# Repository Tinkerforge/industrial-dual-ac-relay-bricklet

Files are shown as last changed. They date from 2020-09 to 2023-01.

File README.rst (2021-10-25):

Industrial Dual AC Relay Bricklet
=================================

This repository contains the firmware source code and the hardware design
files. The documentation generator configs can be found at
https://github.com/Tinkerforge/generators

Repository Content
------------------

software/:
 * examples/: Examples for all supported languages
 * build/: Compiled files
 * src/: Source code of firmware
 * Makefile: Makefile to build project

hardware/:
 * Contains KiCad project files and additionally schematics as PDF

datasheets/:
 * Contains datasheets for sensors and complex ICs that are used

Hardware
--------

The hardware is designed with the open source EDA Suite KiCad
(http://www.kicad.org). Before you are able to open the files,
you have to install the Tinkerforge kicad-libraries
(https://github.com/Tinkerforge/kicad-libraries). You can either clone
them directly in hardware/ or clone them in a separate folder and
symlink them into hardware/
(ln -s kicad_path/kicad-libraries project_path/hardware). After that you
can open the .pro file in hardware/ with KiCad and from there view and
modify the schematics and the PCB layout.

Software
--------

If you want to do your own Brick/Bricklet firmware development we highly
recommend that you use our build environment setup script and read the
tutorial (https://www.tinkerforge.com/en/doc/Tutorials/Tutorial_Build_Environment/Tutorial.html).

To compile the C code we recommend you to install the newest GNU Arm Embedded
Toolchain (https://launchpad.net/gcc-arm-embedded/+download).
You also need to install bricklib2 (https://github.com/Tinkerforge/bricklib2).

You can either clone it directly in software/src/ or clone it in a
separate folder and symlink it into software/src/
(ln -s bricklib_path/bricklib2 project_path/software/src/). Finally make sure to
have CMake installed (http://www.cmake.org/cmake/resources/software.html).

After that you can build the firmware by invoking make in software/.
The firmware (.zbin) can then be found in software/build/ and uploaded
with brickv (click button "Flashing" on start screen).

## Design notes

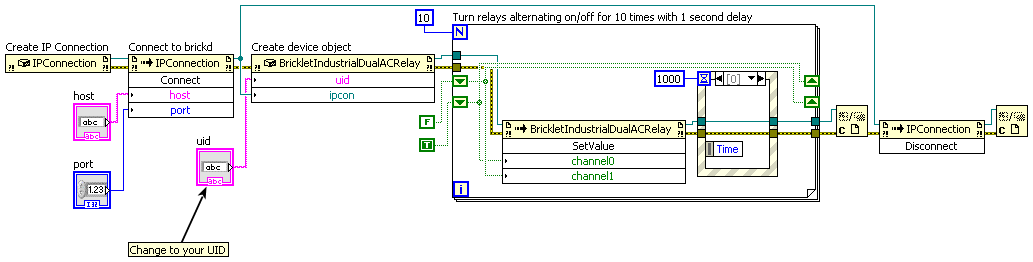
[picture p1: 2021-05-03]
software/examples/labview/Example Simple.vi.png

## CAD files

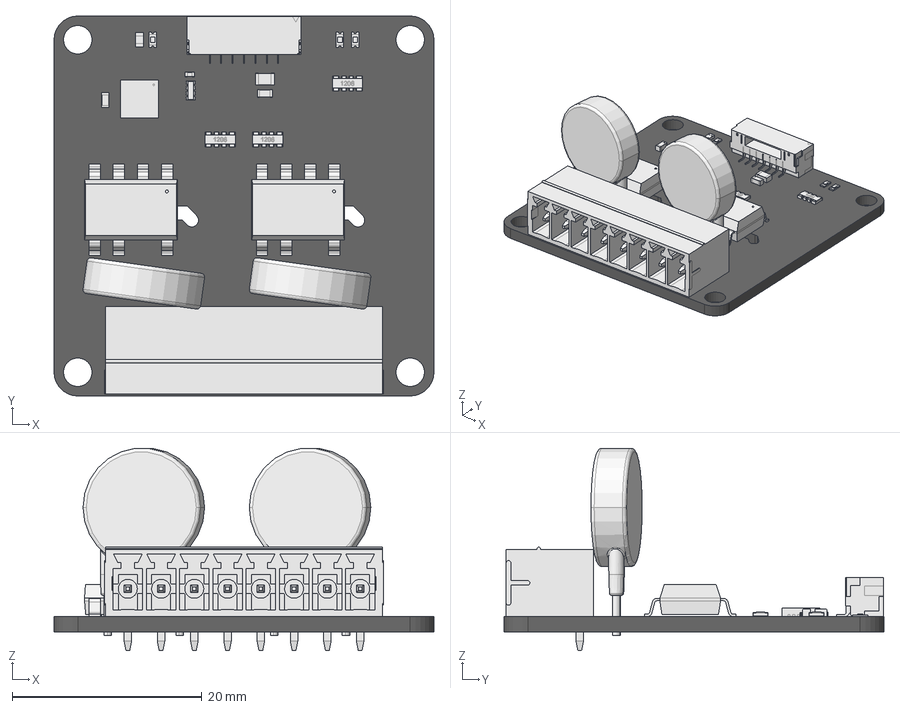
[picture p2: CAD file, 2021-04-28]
hardware/industrial-dual-ac-relay.FCStd
40.0 x 40.0 x 21.3 mm
Pcb_ce84
RP3_Compound_5B27795D
R4_Var_10mm_5F27D5DB
RP2_Cut_5A58BB7E
U1_QFN-24_4x4mm_Pitch0.5mm_5F27E068
C1_C_0603_5B2778F5
C2_C_0402_5B2778FA
C3_C_0805_5B2778FF
C4_C_0603_5B277904
D1_Compound_5B277909
D2_Compound_5F27DD51
D5_Compound_5B27791D
P1_BrickletConn_7pin_5B277922
P2_8er_Phoenix_Buchse_5B27792E
R5_R_0603_5B27794D
RP1_Compound_5B277952
R1_Var_10mm_5F27E3CD
RP4_Compound_5F27D5EB

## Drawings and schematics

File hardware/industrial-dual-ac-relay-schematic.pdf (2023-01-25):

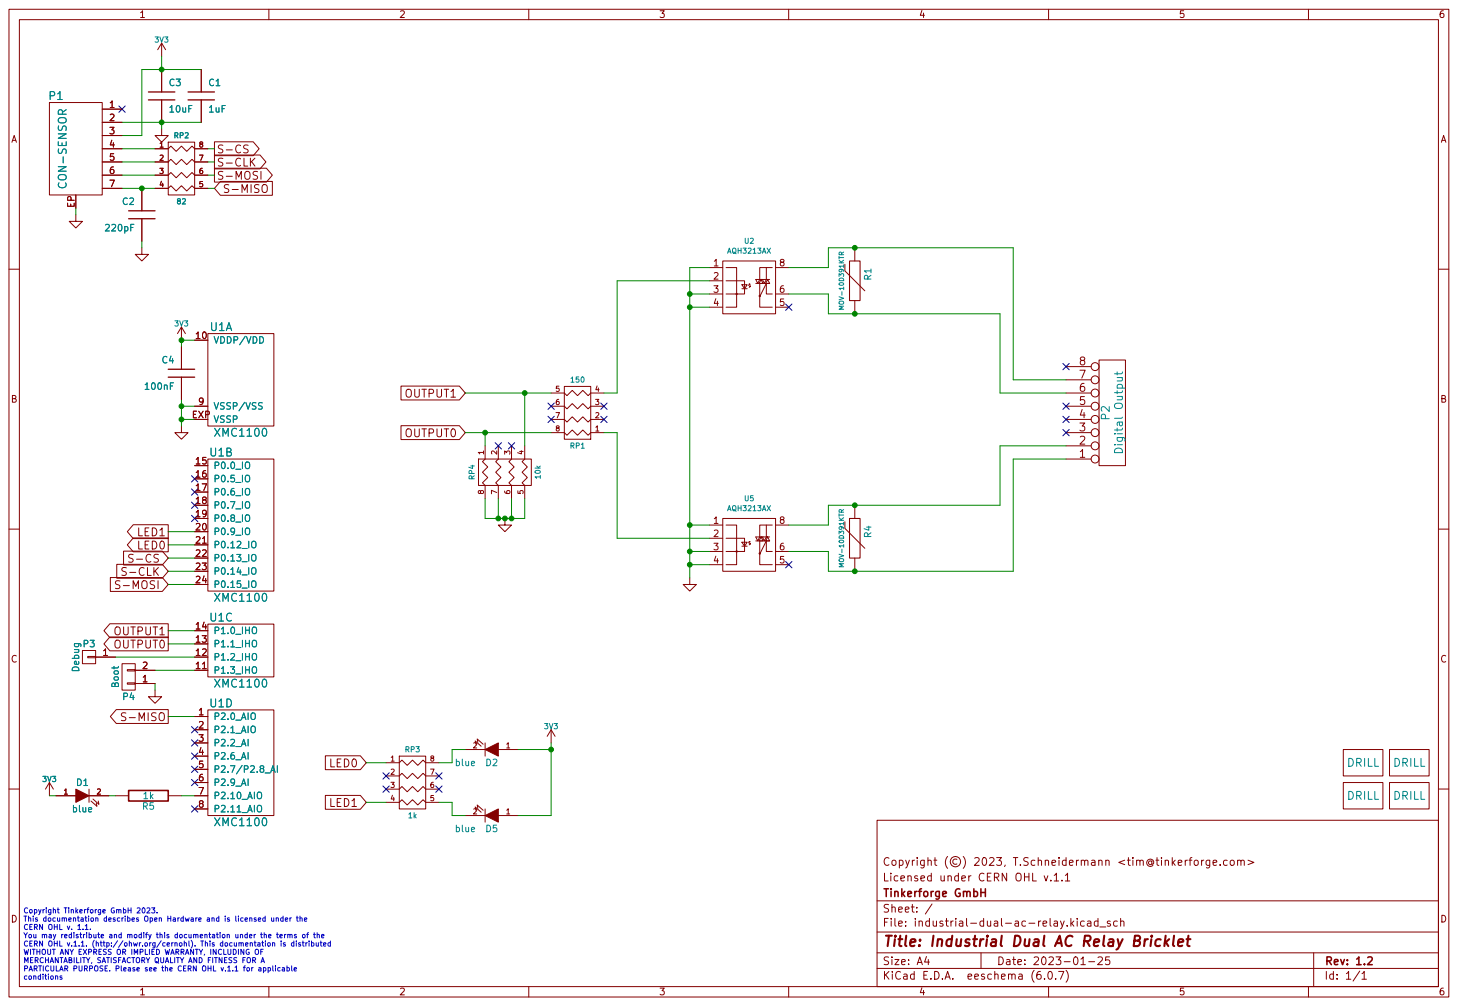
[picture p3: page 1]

Licensed under CERN OHL v.1.1
File: industrial-dual-ac-relay.kicad_sch Sheet: / Tinkerforge GmbH

Copyright Tinkerforge GmbH 2023. This documentation describes Open Hardware and is licensed under the CERN OHL v. 1.1. You may redistribute and modify this documentation under the terms of the CERN OHL v.1.1. (http://ohwr.org/cernohl). This documentation is distributed WITHOUT ANY EXPRESS OR IMPLIED WARRANTY, INCLUDING OF MERCHANTABILITY, SATISFACTORY QUALITY AND FITNESS FOR A

Id: 1/1 Title: Industrial Dual AC Relay Bricklet

PARTICULAR PURPOSE. Please see the CERN OHL v.1.1 for applicable

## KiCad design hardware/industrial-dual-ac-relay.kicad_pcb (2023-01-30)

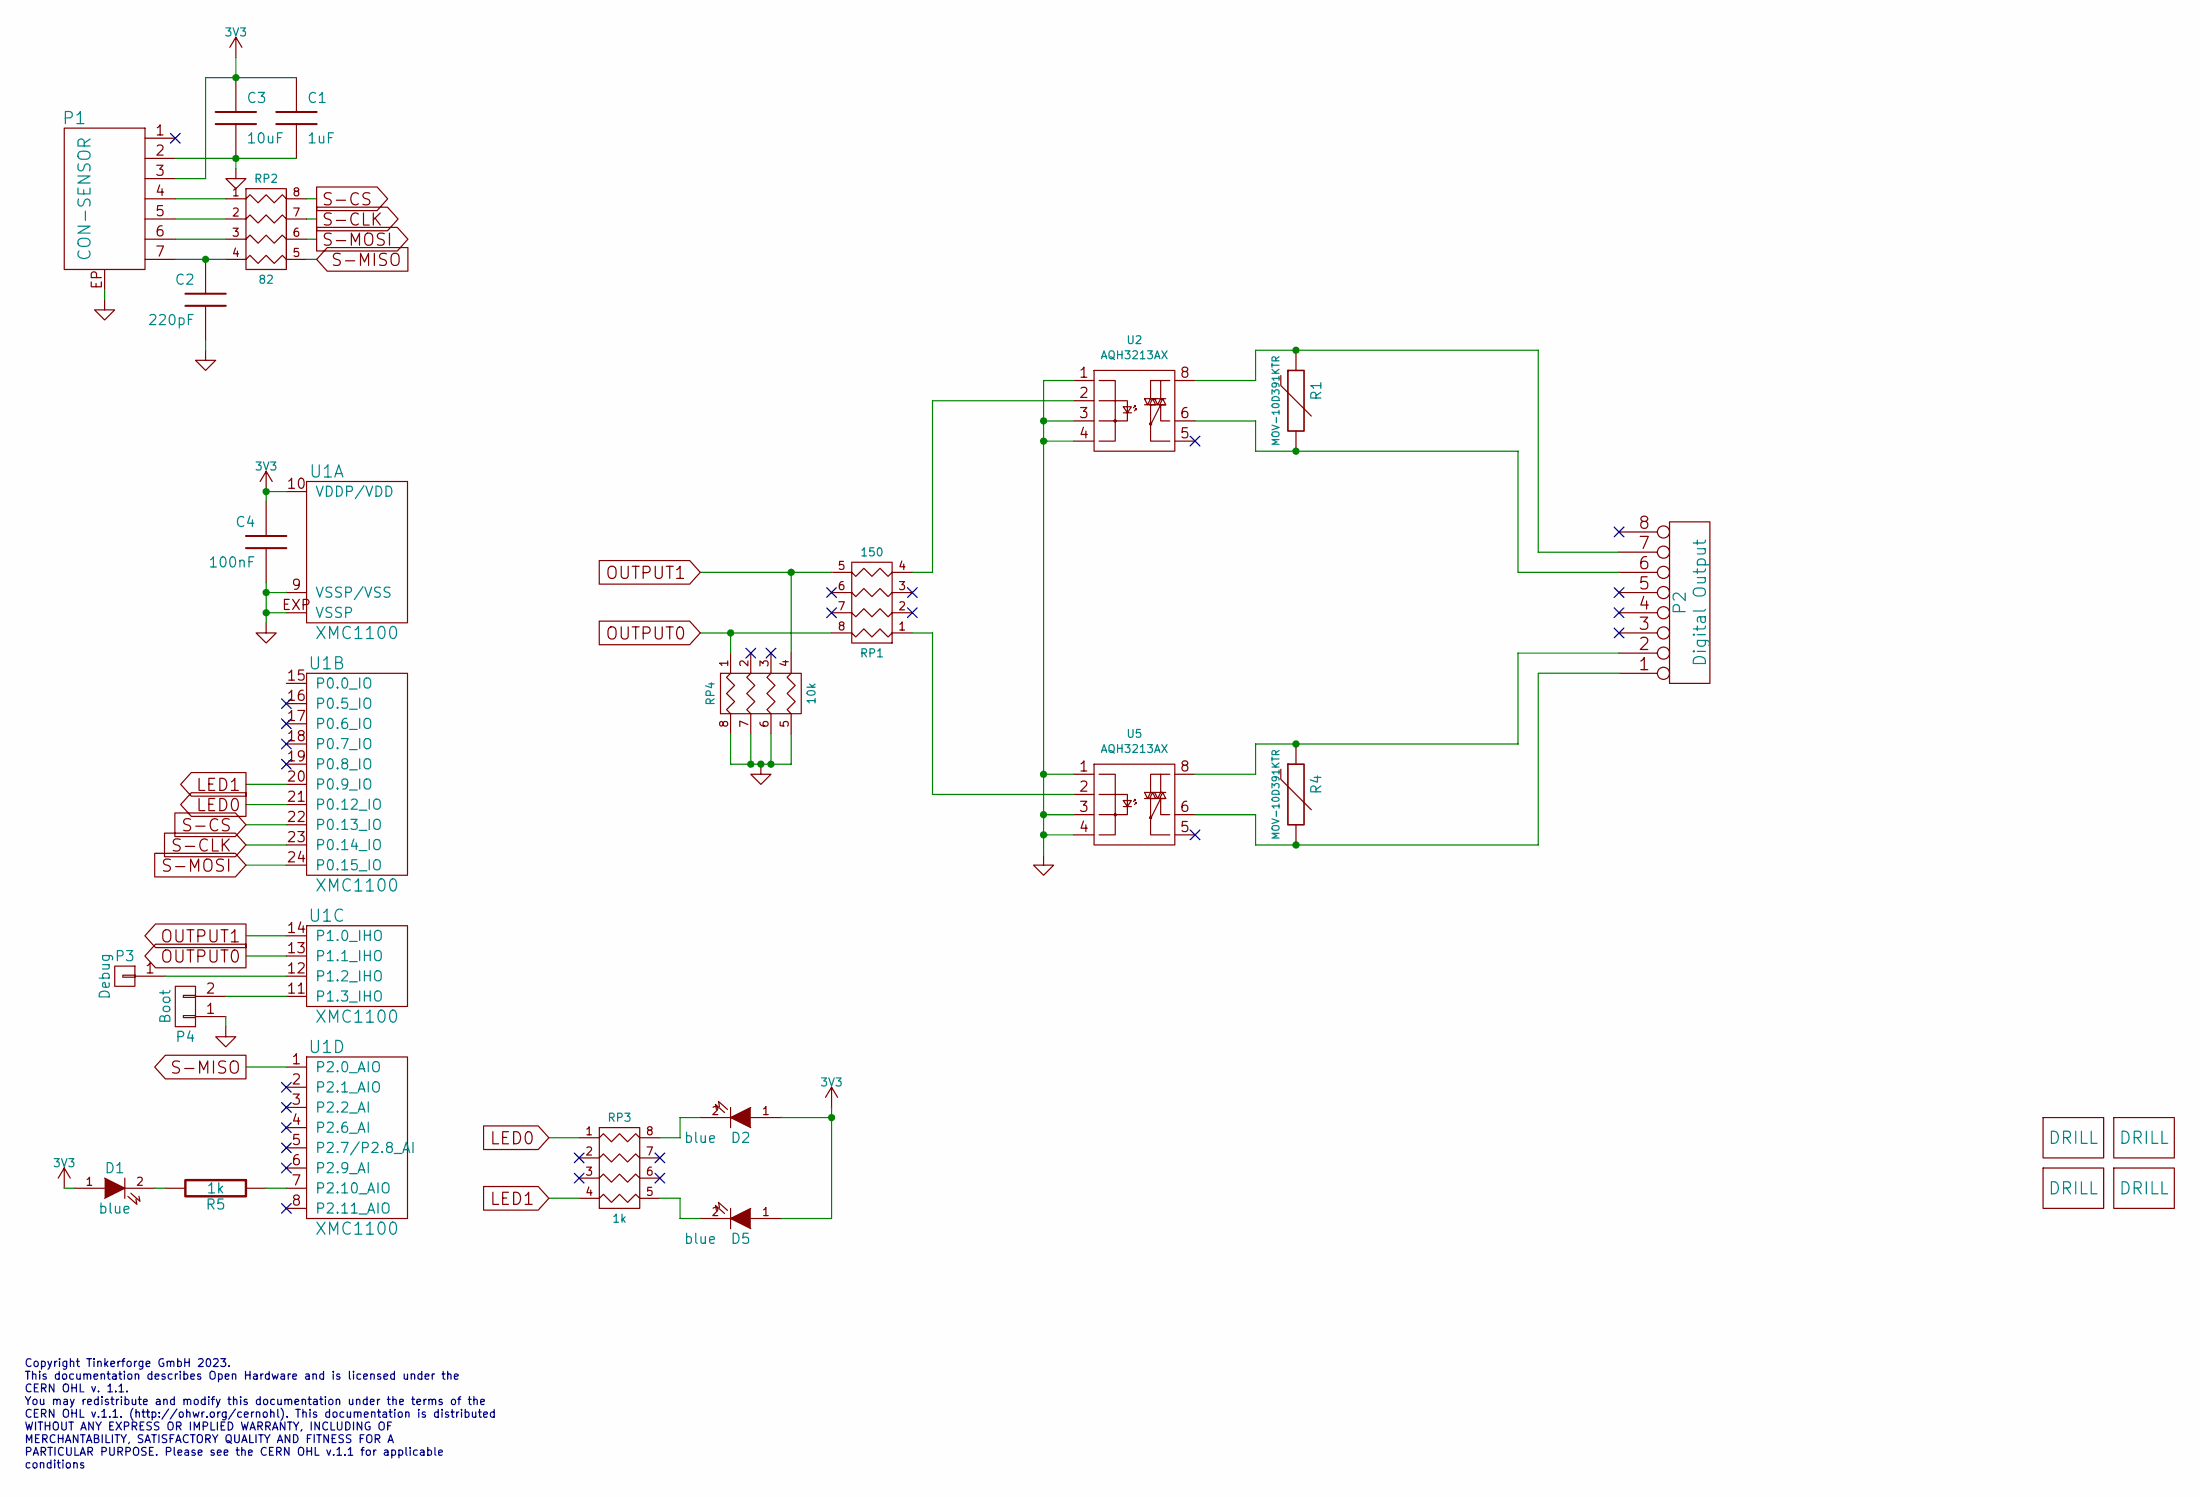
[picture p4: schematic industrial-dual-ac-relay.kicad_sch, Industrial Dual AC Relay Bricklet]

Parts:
C1: 1uF; C0603F
C2: 220pF; C0402F
C3: 10uF; C0805
C4: 100nF; C0603F
D1, D2, D5: blue; D0603F
P1: CON-SENSOR; CON-SENSOR2
P2: Digital Output; OQ_8P_230V
P3: Debug; DEBUG_PAD
P4: Boot; SolderJumper
R1, R4: MOV-10D391KTR; VAR_10mm
R5: 1k; R0603F
RP1: 150; 0603X4
RP2: 82; 4X0402
RP3: 1k; 0603X4
RP4: 10k; 0603X4
U1: XMC1100; QFN24-4x4mm-0.5mm
U2, U5: AQH3213AX; AQ-H
U7, U8, U9: DRILL; DRILL_NP
Ue1: DRILL; DRILL_NP

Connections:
3V3: C1.1, C3.1, C4.1, D1.1 (A), D2.1 (A), D5.1 (A), P1.3, U1.10 (VDDP/VDD)
GND: C1.2, C2.2, C3.2, C4.2, P1.2, P1.EP, P4.1, RP4.5 (R4), RP4.6 (R3), RP4.7 (R2), RP4.8 (R1), U1.9 (VSSP/VSS), U1.EXP (VSSP), U2.1, U2.3, U2.4, U5.1, U5.3, U5.4
LED0: RP3.1, U1.21 (P0.12_IO)
LED1: RP3.4, U1.20 (P0.9_IO)
unnamed: C2.1, P1.7, RP2.4
unnamed: D1.2 (K), R5.2
unnamed: D2.2 (K), RP3.8 (R1)
unnamed: D5.2 (K), RP3.5 (R4)
unnamed: P1.4, RP2.1
unnamed: P1.5, RP2.2
unnamed: P1.6, RP2.3
unnamed: P2.1, R4.2, U5.6
unnamed: P2.2, R4.1, U5.8
unnamed: P2.6, R1.2, U2.6
unnamed: P2.7, R1.1, U2.8
unnamed: P3.1, U1.12 (P1.2_IHO)
unnamed: P4.2, U1.11 (P1.3_IHO)
unnamed: R5.1, U1.7 (P2.10_AIO)
unnamed: RP1.1, U5.2
unnamed: RP1.4, U2.2
OUTPUT0: RP1.8 (R1), RP4.1, U1.13 (P1.1_IHO)
OUTPUT1: RP1.5 (R4), RP4.4, U1.14 (P1.0_IHO)
S-CLK: RP2.7 (R2), U1.23 (P0.14_IO)
S-CS: RP2.8 (R1), U1.22 (P0.13_IO)
S-MISO: RP2.5 (R4), U1.1 (P2.0_AIO)
S-MOSI: RP2.6 (R3), U1.24 (P0.15_IO)

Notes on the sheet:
Copyright Tinkerforge GmbH 2023. This documentation describes Open Hardware and is licensed under the CERN OHL v. 1.1. You may redistribute and modify this documentation under the terms of the CERN OHL v.1.1. (http://ohwr.org/cernohl). This documentation is distributed WITHOUT ANY EXPRESS OR IMPLIE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

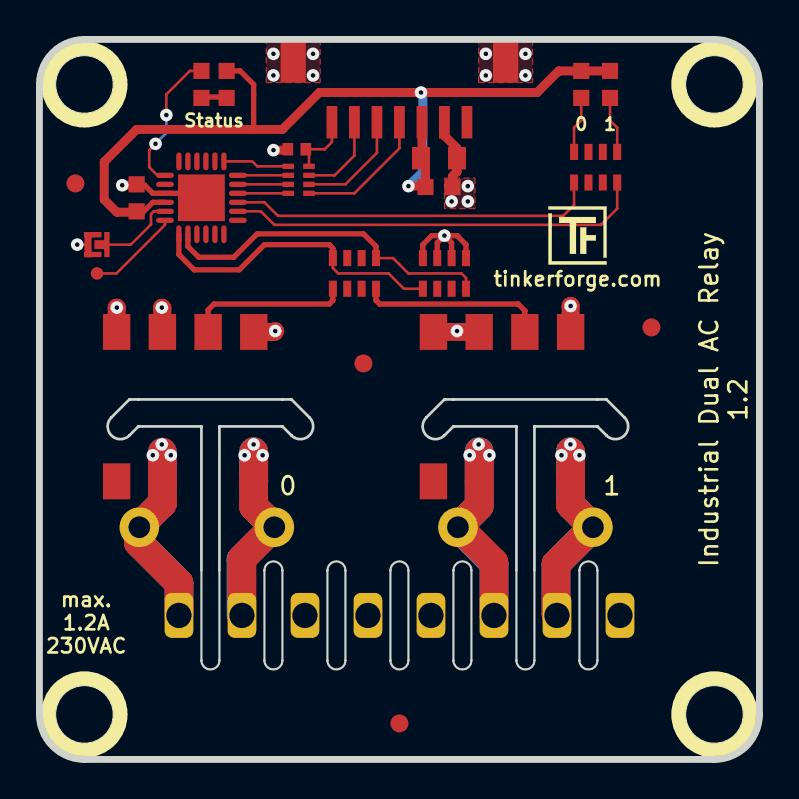
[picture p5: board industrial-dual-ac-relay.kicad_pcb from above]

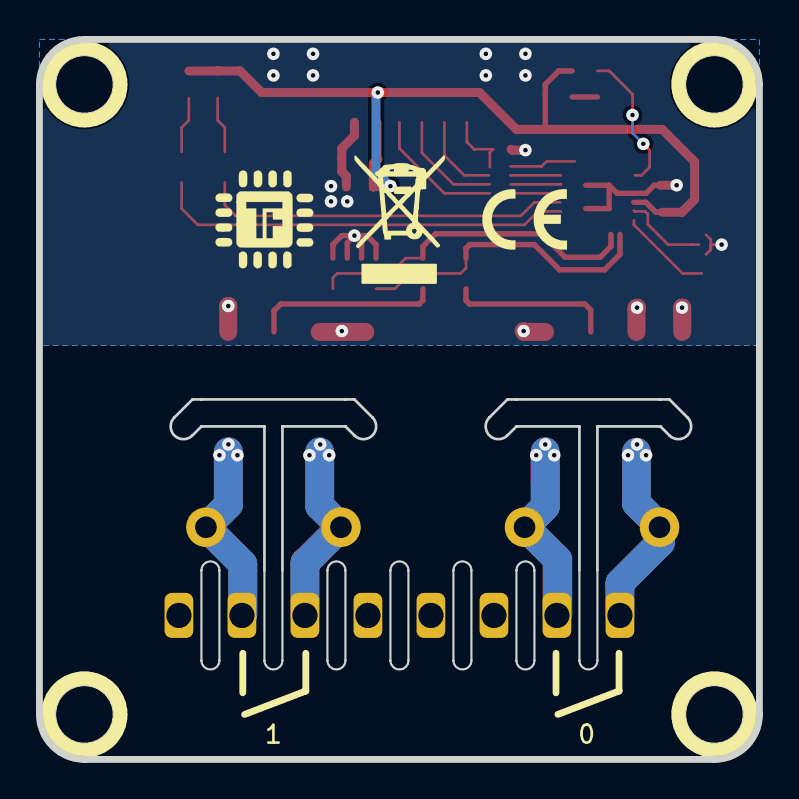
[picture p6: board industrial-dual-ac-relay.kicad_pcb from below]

Board: 2 copper layers, 40.0 x 40.0 mm, 31 parts (2 on the bottom side), 26 nets.

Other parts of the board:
Fiducial_Mark: VAL**; Fiducial_Mark
Fiducial_Mark#2, Fiducial_Mark#3, Fiducial_Mark#4: VAL**; Fiducial_Mark
VAL: WEEE_7mm
VAL#2: CE_5mm

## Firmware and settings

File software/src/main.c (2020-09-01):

/* industrial-dual-ac-relay-bricklet
 * Copyright (C) 2020 Olaf Lüke <olaf@tinkerforge.com>
 *
 * main.c: Initialization for Dual AC Relay V2 Bricklet
 *
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
 * You should have received a copy of the GNU Lesser General Public
 * License along with this library; if not, write to the
 * Free Software Foundation, Inc., 59 Temple Place - Suite 330,
 * Boston, MA 02111-1307, USA.
 */

#include <stdio.h>
#include <stdbool.h>

#include "configs/config.h"

#include "bricklib2/bootloader/bootloader.h"
#include "bricklib2/hal/system_timer/system_timer.h"
#include "communication.h"
#include "relay.h"

int main(void) {
	relay_init();
	communication_init();

	while(true) {
		bootloader_tick();
		communication_tick();
		relay_tick();
	}
}

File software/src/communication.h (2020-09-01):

/* industrial-dual-ac-relay-bricklet
 * Copyright (C) 2020 Olaf Lüke <olaf@tinkerforge.com>
 *
 * communication.h: TFP protocol message handling
 *
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
 * You should have received a copy of the GNU Lesser General Public
 * License along with this library; if not, write to the
 * Free Software Foundation, Inc., 59 Temple Place - Suite 330,
 * Boston, MA 02111-1307, USA.
 */

#ifndef COMMUNICATION_H
#define COMMUNICATION_H

#include <stdint.h>
#include <stdbool.h>

#include "bricklib2/protocols/tfp/tfp.h"
#include "bricklib2/bootloader/bootloader.h"

// Default functions
BootloaderHandleMessageResponse handle_message(const void *data, void *response);
void communication_tick(void);
void communication_init(void);

// Constants

#define INDUSTRIAL_DUAL_AC_RELAY_CHANNEL_LED_CONFIG_OFF 0
#define INDUSTRIAL_DUAL_AC_RELAY_CHANNEL_LED_CONFIG_ON 1
#define INDUSTRIAL_DUAL_AC_RELAY_CHANNEL_LED_CONFIG_SHOW_HEARTBEAT 2
#define INDUSTRIAL_DUAL_AC_RELAY_CHANNEL_LED_CONFIG_SHOW_CHANNEL_STATUS 3

#define INDUSTRIAL_DUAL_AC_RELAY_BOOTLOADER_MODE_BOOTLOADER 0
#define INDUSTRIAL_DUAL_AC_RELAY_BOOTLOADER_MODE_FIRMWARE 1
#define INDUSTRIAL_DUAL_AC_RELAY_BOOTLOADER_MODE_BOOTLOADER_WAIT_FOR_REBOOT 2
#define INDUSTRIAL_DUAL_AC_RELAY_BOOTLOADER_MODE_FIRMWARE_WAIT_FOR_REBOOT 3
#define INDUSTRIAL_DUAL_AC_RELAY_BOOTLOADER_MODE_FIRMWARE_WAIT_FOR_ERASE_AND_REBOOT 4

#define INDUSTRIAL_DUAL_AC_RELAY_BOOTLOADER_STATUS_OK 0
#define INDUSTRIAL_DUAL_AC_RELAY_BOOTLOADER_STATUS_INVALID_MODE 1
#define INDUSTRIAL_DUAL_AC_RELAY_BOOTLOADER_STATUS_NO_CHANGE 2
#define INDUSTRIAL_DUAL_AC_RELAY_BOOTLOADER_STATUS_ENTRY_FUNCTION_NOT_PRESENT 3
#define INDUSTRIAL_DUAL_AC_RELAY_BOOTLOADER_STATUS_DEVICE_IDENTIFIER_INCORRECT 4
#define INDUSTRIAL_DUAL_AC_RELAY_BOOTLOADER_STATUS_CRC_MISMATCH 5

#define INDUSTRIAL_DUAL_AC_RELAY_STATUS_LED_CONFIG_OFF 0
#define INDUSTRIAL_DUAL_AC_RELAY_STATUS_LED_CONFIG_ON 1
#define INDUSTRIAL_DUAL_AC_RELAY_STATUS_LED_CONFIG_SHOW_HEARTBEAT 2
#define INDUSTRIAL_DUAL_AC_RELAY_STATUS_LED_CONFIG_SHOW_STATUS 3

// Function and callback IDs and structs
#define FID_SET_VALUE 1
#define FID_GET_VALUE 2
#define FID_SET_CHANNEL_LED_CONFIG 3
#define FID_GET_CHANNEL_LED_CONFIG 4
#define FID_SET_MONOFLOP 5
#define FID_GET_MONOFLOP 6
#define FID_SET_SELECTED_VALUE 8

#define FID_CALLBACK_MONOFLOP_DONE 7

typedef struct {
	TFPMessageHeader header;
	bool channel0;
	bool channel1;
} __attribute__((__packed__)) SetValue;

typedef struct {
	TFPMessageHeader header;
} __attribute__((__packed__)) GetValue;

typedef struct {
	TFPMessageHeader header;
	bool channel0;
	bool channel1;
} __attribute__((__packed__)) GetValue_Response;

typedef struct {
	TFPMessageHeader header;
	uint8_t channel;
	uint8_t config;
} __attribute__((__packed__)) SetChannelLEDConfig;

typedef struct {
	TFPMessageHeader header;
	uint8_t channel;
} __attribute__((__packed__)) GetChannelLEDConfig;

typedef struct {
	TFPMessageHeader header;
	uint8_t config;
} __attribute__((__packed__)) GetChannelLEDConfig_Response;

typedef struct {
	TFPMessageHeader header;
	uint8_t channel;
	bool value;
	uint32_t time;
} __attribute__((__packed__)) SetMonoflop;

typedef struct {
	TFPMessageHeader header;
	uint8_t channel;
} __attribute__((__packed__)) GetMonoflop;

typedef struct {
	TFPMessageHeader header;
	bool value;
	uint32_t time;
	uint32_t time_remaining;
} __attribute__((__packed__)) GetMonoflop_Response;

typedef struct {
	TFPMessageHeader header;
	uint8_t channel;
	bool value;
} __attribute__((__packed__)) MonoflopDone_Callback;

typedef struct {
	TFPMessageHeader header;
	uint8_t channel;
	bool value;
} __attribute__((__packed__)) SetSelectedValue;


// Function prototypes
BootloaderHandleMessageResponse set_value(const SetValue *data);
BootloaderHandleMessageResponse get_value(const GetValue *data, GetValue_Response *response);
BootloaderHandleMessageResponse set_channel_led_config(const SetChannelLEDConfig *data);
BootloaderHandleMessageResponse get_channel_led_config(const GetChannelLEDConfig *data, GetChannelLEDConfig_Response *response);
BootloaderHandleMessageResponse set_monoflop(const SetMonoflop *data);
BootloaderHandleMessageResponse get_monoflop(const GetMonoflop *data, GetMonoflop_Response *response);
BootloaderHandleMessageResponse set_selected_value(const SetSelectedValue *data);

// Callbacks
bool handle_monoflop_done_callback(void);

#define COMMUNICATION_CALLBACK_TICK_WAIT_MS 1
#define COMMUNICATION_CALLBACK_HANDLER_NUM 1
#define COMMUNICATION_CALLBACK_LIST_INIT \
	handle_monoflop_done_callback, \


#endif

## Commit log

2020-08-03 initial push
    [industrial-dual-ac-relay.kicad_pcb, industrial-dual-ac-relay.sch]
2020-08-04 ready for prototype
    [industrial-dual-ac-relay.kicad_pcb, industrial-dual-ac-relay.sch]
2020-08-19 Version V1.1 : Changed pins to highoutput, changed resistor order
    [industrial-dual-ac-relay.kicad_pcb, industrial-dual-ac-relay.sch]
2020-09-01 Add Industrial Dual AC Relay Bricklet firmware implementation
    [cmake_config_custom.txt]
2020-09-01 Add support for channel LEDs
2020-09-02 uc: Add example driver note.
2020-09-17 Fix relay/pin defines
2021-04-28 fix 3d view, add schematic
    [industrial-dual-ac-relay.kicad_pcb]
2021-04-28 fix 3d path
    [industrial-dual-ac-relay.kicad_pcb]
2021-04-28 add 3d data
    [industrial-dual-ac-relay.FCStd]
2021-10-25 Update KiCad link
    https://www.kicad.org/blog/2021/10/Avoid-links-to-former-kicad-domain/
2022-04-27 uc: Adapt to bindings changes
    [example_simple.c]
2022-11-15 changed to KiCad 6, changed OQ footprint for more clearence
    [industrial-dual-ac-relay.kicad_pcb, industrial-dual-ac-relay.kicad_sch, industrial-dual-ac-relay.sch]
2022-11-17 extented the clearance slits
    [industrial-dual-ac-relay.kicad_pcb]
2022-11-17 Prototype V1.2
    [industrial-dual-ac-relay.kicad_pcb]
2023-01-23 New standart layout
    [industrial-dual-ac-relay.kicad_pcb]
2023-01-25 Data cleanup
    [industrial-dual-ac-relay.kicad_pcb, industrial-dual-ac-relay.kicad_sch]
2023-01-30 added fiducials
    [industrial-dual-ac-relay.kicad_pcb]

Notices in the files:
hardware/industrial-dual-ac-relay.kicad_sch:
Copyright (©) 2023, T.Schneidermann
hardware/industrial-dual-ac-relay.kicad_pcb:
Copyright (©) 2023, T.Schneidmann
